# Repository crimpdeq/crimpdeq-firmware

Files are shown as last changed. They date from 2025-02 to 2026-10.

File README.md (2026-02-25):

# Crimpdeq Firmware




Meet [Crimpdeq](https://crimpdeq.com), a portable digital force sensor designed for climbers, coaches, and therapists to measure and train finger strength, pulling power, and endurance.

Crimpdeq is a fully open-source project based on an [ESP32-C3](https://github.com/esp-rs/esp-rust-board) and a WH-C100 crane scale, with firmware fully written in Rust!

> [!NOTE]
> If you're interested in reproducing this project or giving it a try, please, reach out! You can contact me via email (sergio.gasquez@gmail.com), [Twitter](https://x.com/Sergio_Gasquez) or [Bluesky](https://bsky.app/profile/sergiogasquez.bsky.social).

## Specs

- Rechargeable battery with USB‑C charging
- Communicates via Bluetooth Low Energy (BLE)
- Open-source firmware written in Rust
- Open-source PCB design
- Open-source 3D case design
- Automatic sleep when inactive
- Compatible with Tindeq Progressor app ([Android](https://play.google.com/store/apps/details?id=com.progressor&hl=es_419) | [iOS](https://apps.apple.com/es/app/tindeq-progressor/id1380412428))
- Compatible with Frez app (formerly ClimbHarder) ([Android](https://play.google.com/store/apps/details?id=com.holdtight.climbharder&pcampaignid=web_share) | [iOS](https://apps.apple.com/us/app/climbharder-no-hang-training/id6730120024))
- Sampling frequency: 80 Hz
- Design load: 1500 N (≈150 kg), full scale
- Precision:
    - 0.05 kg between 0 and 99 kg
    - 0.1 kg between 100 and 150 kg
- Operating temperature: 0–40 °C
- Dimensions: 80 × 90 × 35 mm
- Uses the [Tindeq Progressor API](https://tindeq.com/progressor_api/)

## Building and Running the Firmware

The [Crimpdeq Book](https://book.crimpdeq.com/) covers assembly, calibration, charging, and general usage. For repository-specific instructions, see the [Firmware](https://book.crimpdeq.com/firmware.html) chapter for prerequisites, how to build, flash, and run the firmware, how to enable logs, and troubleshooting.

## Contributing
Contributions are welcome! Feel free to:
- Submit PRs for bug fixes or new features
- Test and report issues
- Suggest improvements to documentation

## Issues
If you encounter any issue or want to leave any feedback, please [open an issue](https://github.com/crimpdeq/crimpdeq-firmware/issues/new)

## License
This repository is licensed under either of:

- Apache License, Version 2.0 ([LICENSE-APACHE](LICENSE-APACHE) or http://www.apache.org/licenses/LICENSE-2.0)
- MIT license ([LICENSE-MIT](LICENSE-MIT) or http://opensource.org/licenses/MIT)

at your option.

## Kudos
- @bjoernQ for helping me during the development and developing the [`bleps`](https://github.com/bjoernQ/bleps) crate, which was fundamental for this project.
- [hangman](https://github.com/kesyog/hangman) for being an improved version of this project and a great source of inspiration for this project.
- Tindeq for having its API public and allowing for projects like this to exist!

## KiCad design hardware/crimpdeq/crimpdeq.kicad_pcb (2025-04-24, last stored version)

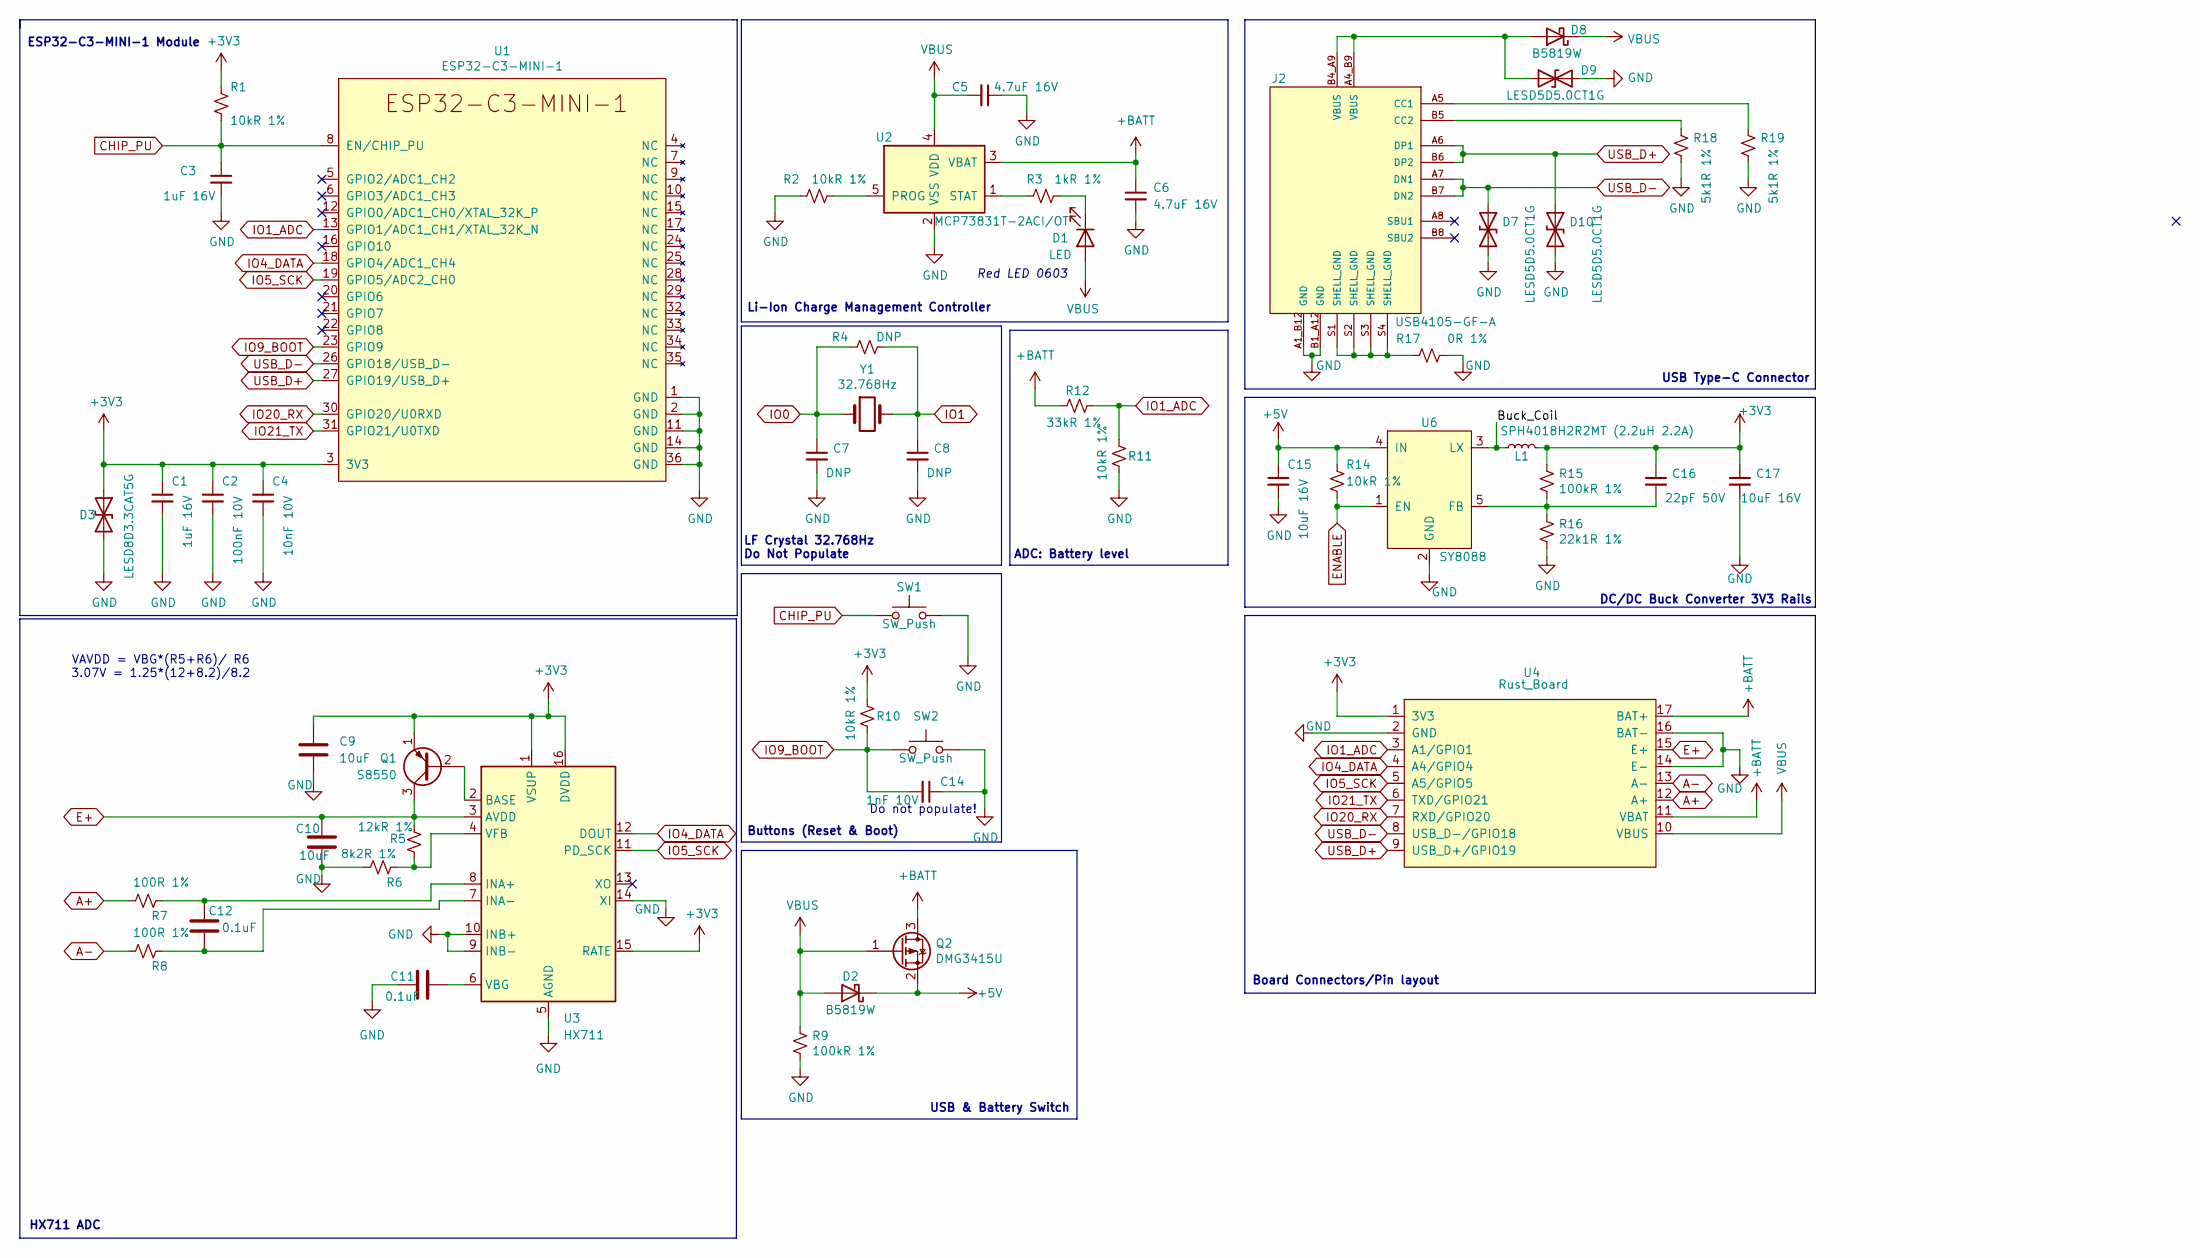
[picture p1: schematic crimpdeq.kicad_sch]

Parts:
C1, C3: 1uF 16V; C_0402_1005Metric; LCSC C52923
C2: 100nF 10V; C_0402_1005Metric; LCSC C1525
C4: 10nF 10V; C_0402_1005Metric; LCSC C15195
C5, C6: 4.7uF 16V; C_0603_1608Metric; LCSC C19666
C7, C8: DNP; C_0402_1005Metric
C9, C10: 10uF; C_0603_1608Metric
C11, C12: 0.1uF; C_0603_1608Metric
C14: 1nF 10V; C_0402_1005Metric; LCSC C1523
C15, C17: 10uF 16V; C_0805_2012Metric; LCSC C15850
C16: 22pF 50V; C_0603_1608Metric; LCSC C1653
D1: LED; LED_0603_1608Metric; LCSC C2286
D2, D8: B5819W; D_SOD-123; LCSC C8598
D3: LESD8D3.3CAT5G; D_SOD-882; LCSC C172409
D7, D9, D10: LESD5D5.0CT1G; D_SOD-523; LCSC C383211
J2: USB4105-GF-A; GCT_USB4105-GF-A; PARTREV A3; LCSC C165948
L1: SPH4018H2R2MT (2.2uH 2.2A); L_Bourns-SRN4018; LCSC C370436
Q1: S8550; TO-92_Inline
Q2: DMG3415U; SOT-23; LCSC C96616
R1, R2, R10, R11, R14: 10kR 1%; R_0402_1005Metric; LCSC C25744
R3: 1kR 1%; R_0402_1005Metric; LCSC C11702
R4: DNP; R_0402_1005Metric
R5: 12kR 1%; R_0402_1005Metric; LCSC C25741
R6: 8k2R 1%; R_0402_1005Metric; LCSC C25741
R7, R8: 100R 1%; R_0402_1005Metric; LCSC C25741
R9, R15: 100kR 1%; R_0402_1005Metric; LCSC C25741
R12: 33kR 1%; R_0402_1005Metric; LCSC C25744
R16: 22k1R 1%; R_0402_1005Metric; LCSC C43473
R17: 0R 1%; R_0402_1005Metric; LCSC C17168
R18, R19: 5k1R 1%; R_0402_1005Metric; LCSC C25905
SW1, SW2: SW_Push; SW_SPST_PTS810; LCSC C116501
U1: ESP32-C3-MINI-1; LCSC C2838502
U2: MCP73831T-2ACI/OT; SOT-23-5; LCSC C424093
U3: HX711; SOP-16_3.9x9.9mm_P1.27mm
U4: Rust_Board
U6: SY8088; SOT-23-5; LCSC C479072
Y1: 32.768Hz; Crystal_SMD_3215-2Pin_3.2x1.5mm

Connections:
+3V3: C1.1, C2.1, C4.1, C9.1, C16.1, C17.1, D3.1 (A1), L1.2, Q1.1 (E), R1.1, R10.1, R15.1, U1.3 (3V3), U3.1 (VSUP), U3.15 (RATE), U3.16 (DVDD), U4.1 (3V3)
+5V: C15.1, D2.1 (K), Q2.2 (S), R14.1, U6.4 (IN)
+BATT: C6.1, Q2.3 (D), R12.1, U2.3 (VBAT), U4.11 (VBAT), U4.17 (BAT+)
/Buck_Coil: L1.1, U6.3 (LX)
A+: R7.2, U4.12 (A+)
A-: R8.2, U4.13 (A-)
CHIP_PU: C3.1, R1.2, SW1.1, U1.8 (EN/CHIP_PU)
E+: C10.1, Q1.3 (C), R5.1, U3.3 (AVDD), U4.15 (E+)
ENABLE: R14.2, U6.1 (EN)
GND: C1.2, C2.2, C3.2, C4.2, C5.1, C6.2, C7.2, C8.2, C9.2, C10.2, C11.1, C14.1, C15.2, C17.2, D3.2 (A2), D7.2 (A2), D9.2 (A2), D10.2 (A2), J2.A1_B12 (GND), J2.B1_A12 (GND), R2.1, R6.2, R9.2, R11.2, R16.2, R17.2, R18.2, R19.2, SW1.2, SW2.2, U1.1 (GND), U1.2 (GND), U1.11 (GND), U1.14 (GND), U1.36 (GND), U1.49, U2.2 (VSS), U3.5 (AGND), U3.9 (INB-), U3.10 (INB+), U3.14 (XI), U4.2 (GND), U4.14 (E-), U4.16 (BAT-), U6.2 (GND)
IO0: C7.1, R4.1, Y1.1
IO1: C8.1, R4.2, Y1.2
IO1_ADC: R11.1, R12.2, U1.13 (GPIO1/ADC1_CH1/XTAL_32K_N), U4.3 (A1/GPIO1)
IO4_DATA: U1.18 (GPIO4/ADC1_CH4), U3.12 (DOUT), U4.4 (A4/GPIO4)
IO5_SCK: U1.19 (GPIO5/ADC2_CH0), U3.11 (PD_SCK), U4.5 (A5/GPIO5)
IO9_BOOT: C14.2, R10.2, SW2.1, U1.23 (GPIO9)
IO20_RX: U1.30 (GPIO20/U0RXD), U4.7 (RXD/GPIO20)
IO21_TX: U1.31 (GPIO21/U0TXD), U4.6 (TXD/GPIO21)
unnamed: D1.1 (K), R3.2
unnamed: D8.2 (A), D9.1 (A1), J2.A4_B9 (VBUS), J2.B4_A9 (VBUS)
unnamed: J2.A5 (CC1), R19.1
unnamed: J2.B5 (CC2), R18.1
unnamed: J2.S1 (SHELL_GND), J2.S2 (SHELL_GND), J2.S3 (SHELL_GND), J2.S4 (SHELL_GND), R17.1
unnamed: Q1.2 (B), U3.2 (BASE)
unnamed: R2.2, U2.5 (PROG)
unnamed: R3.1, U2.1 (STAT)
unnamed: C12.1, R7.1, U3.8 (INA+)
unnamed: C12.2, R8.1, U3.7 (INA-)
unnamed: C11.2, U3.6 (VBG)
unnamed: R5.2, R6.1, U3.4 (VFB)
unnamed: C16.2, R15.2, R16.1, U6.5 (FB)
USB_D+: D10.1 (A1), J2.A6 (DP1), J2.B6 (DP2), U1.27 (GPIO19/USB_D+), U4.9 (USB_D+/GPIO19)
USB_D-: D7.1 (A1), J2.A7 (DN1), J2.B7 (DN2), U1.26 (GPIO18/USB_D-), U4.8 (USB_D-/GPIO18)
VBUS: C5.2, D1.2 (A), D2.2 (A), D8.1 (K), Q2.1 (G), R9.1, U2.4 (VDD), U4.10 (VBUS)

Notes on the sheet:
ADC: Battery level
USB Type-C Connector
VAVDD = VBG*(R5+R6)/ R6 3.07V = 1.25*(12+8.2)/8.2
Board Connectors/Pin layout
Li-Ion Charge Management Controller
USB & Battery Switch
Do not populate!
Red LED 0603
Buttons (Reset & Boot)
HX711 ADC
ESP32-C3-MINI-1 Module
LF Crystal 32.768Hz Do Not Populate
DC/DC Buck Converter 3V3 Rails

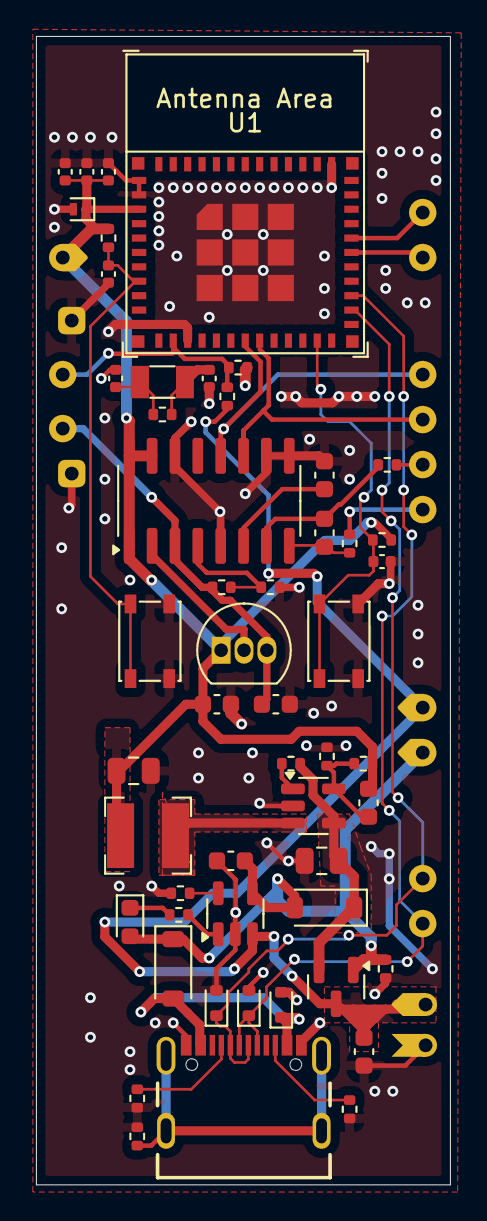
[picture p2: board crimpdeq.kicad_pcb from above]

Board: 2 copper layers, 23.0 x 63.8 mm, 53 parts (0 on the bottom side), 34 nets.

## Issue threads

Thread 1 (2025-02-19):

Improve taring

SergioGasquez, 2025-02-19:
At the moment, the taring mechanism is not ideal, and in the Tindeq app, when switching hands, it gets tared, which results in having it wrongly tared.

SergioGasquez, 2025-03-03:
Also, we should avoid taring if the calibration offset and factor are the defaults

Closed 2025-03-03.

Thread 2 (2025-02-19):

Improve calibration

SergioGasquez, 2025-02-19:
At the moment we don't really calibrate, we just have a [hardcoded value](https://github.com/SergioGasquez/crimpdeq/blob/main/src/bin/main.rs#L66-L67)  as a scale, this value might work for some values, but with higher weights it may not be correct

Closed 2025-02-21.

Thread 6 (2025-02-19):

Evaluate which sampling frequency the HX711 should use

SergioGasquez, 2025-02-19:
If we connect the `RATE` signal of the HX711 to 3.3v, it samples at 80 Hz instead of 10 Hz. See `Table 1 Pin Description` of [Datasheet](https://cdn.sparkfun.com/datasheets/Sensors/ForceFlex/hx711_english.pdf)

Closed 2025-02-26.

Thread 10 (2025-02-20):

Remove unnecesary exposed pins

SergioGasquez, 2025-02-20:
At the moment, the board exposes, via holes, many unnecessary pins. Deleting them would result in less pads and a simpler pcb

Closed 2025-02-26.

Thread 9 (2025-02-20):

Allow connecting a switch to power on/off the device

SergioGasquez, 2025-02-20:
This should be achieved by leaving two holes, where we could solder, two wires that go to the switch. Those 2 holes should be connected to the battery pins.

Closed 2025-02-26.

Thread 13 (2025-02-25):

Update HX711 sampling frequency

SergioGasquez, 2025-02-25:
HX711 can sample at 10Hz and 80Hz, depending on the `RATE` pin value (` 0: 10Hz; 1: 80Hz `). The PCB should use 80 Hz as RFD test only makes sense with high sampling freq.

SergioGasquez, 2025-02-26:
Closed in favor of #13

Closed 2025-02-26.

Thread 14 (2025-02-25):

Evaluate using NAU7802

SergioGasquez, 2025-02-25:
NAU7802 can sample up to 320Hz which is 4 times what HX711 offers:

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

This is very important for an accurate RFD measurement (which usually requires 200/500 Hz). NAU7802 also more expensive than HX711

Closed 2025-02-25.

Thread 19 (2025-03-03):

Add a ControlPoint to reset calibration values

SergioGasquez, 2025-03-03:
The control point should set offset to `0.0` and factor to `1.0`

SergioGasquez, 2025-03-04:
Also, instead of having this we could have a `read_unclaibrated()` method that is used when getting the measured value for the calibration points

Closed 2025-03-27.

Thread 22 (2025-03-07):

thoughts on the schematics

abbbe, 2025-03-07:
I have noticed you use a 1K resistor at ADC input. I am not sure it is a good practice, I mean both use of a single resistor and use of such a high value. I wonder if you saw https://cdn.sparkfun.com/assets/learn_tutorials/3/7/4/SparkFun_openScale_schematic.pdf. Their design -- with two 100R resistors on the inputs -- looks quite sensible. Also note a choke on the excitation line.

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

You are powering HX711 with 3.3V. Supposedly the chip supports this voltage, but many load cells actually rated for higher excitation voltage. No real clue what is the impact in practice, cannot offer any real insight... Just something I was pondering in background as I was also thinking about making custom ESP32+NX711 PCB. This might be useful: https://hackaday.io/project/1741-honeybee-hive-monitoring/log/9780-modifying-the-hx711-breakout-board-for-33v-operation.

Closed 2025-04-24.

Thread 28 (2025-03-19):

Question: Is CALIBRATION_OFFSET needed when using tare?

Yelvd, 2025-03-19:
Calibrated value is calculated using:
```
let raw_value = self.read_raw() - self.tare_value;
let calibrated_value = raw_value as f32 * self.calibration.factor - self.calibration.offset;
```

I am wondering if the `self.calibration.offset` and `self.tare_value` are not both doing the same thing.

Based on the example below, it seems that taring removes the need for the calibration offset

## Example
Assuming the following calibration factors
```
const CALIBRATION_FACTOR: f32 = 0.5;
const CALIBRATION_OFFSET: f32 = 100;
```

### Without Tare:
```
raw_value = read_raw - tare_value = 200 - 0;
calibrated_value = raw_value * calibration.value - calibration.offset =  200 * 0.5 - 100 = 0;
```
This is correct expected behavior.

### With Tare:
tare_value = 200
```
raw_value = read_raw - tare_value = 200 - 200;
calibrated_value = raw_value * calibration.value - calibration.offset =  0 * 0.5 - 100 = -100;
```
Incorrect value.

Yelvd, 2025-03-20:
Thanks for the information. See what the idea is.

To me it looks like at the moment taring is doing both jobs, i.e., the calibration_offset is removed twice.

If that is true, I think there are two main options:

1. Remove CALIBRATION_OFFSET and keep tare as is
2. Keep CALIBRATION_OFFSET, but calculate the tare value over the calibrated value, and remove from calibrated value (instead of from the raw). Because then the tare_value without added weight is 0, so the result would be correct.
 Something like:
```
     // self.tare = is avg of calibrated_value
     let raw_value = self.read_raw();
     let calibrated_value = raw_value as f32 * self.calibration.factor - self.calibration.offset;
     let tared_value = calibrated_value - self.tare_value
```

I don't think any one option is more accurate than the other. And I can imagine that there might be some cases where having the CALIBRATION_OFFSET is useful. But I do think that the current implementation is not fully accurate. But if my logic is wrong, and the current calculation is accurate, then there is no problem.

Closed 2025-07-04.

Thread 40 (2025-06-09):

Wrong values after calibration

Bobr7772, 2025-06-09:
I am following guide book on calibration,but still getting issues with correct weight displayment.

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
+-28kg of added weight
My current calibration cycle:
No weight - 7300000000 - send - hanging weight  -- 7341e0cccd - send - weight release.

SergioGasquez, 2025-06-13:
> I will try

Let me know how it goes!

Bobr7772, 2025-06-13:
How can I put grams instead of kg? I have 28 kg kettlebell,so I will need to put 0x4888b800 into a calibration app?

Bobr7772, 2025-06-14:
I am still getting wrong values.
https://streamable.com/jro9bn video with calibration

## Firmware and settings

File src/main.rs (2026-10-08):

#![no_std]
#![no_main]

use core::cell::RefCell;

use bt_hci::{
    cmd::le::{LeConnUpdate, LeReadLocalSupportedFeatures},
    controller::{ControllerCmdAsync, ControllerCmdSync, ExternalController},
};
use critical_section::Mutex;
use defmt::{debug, error, info, warn};
use embassy_executor::Spawner;
use embassy_futures::{
    join::join,
    select::{Either, select, select3},
};
use embassy_sync::{blocking_mutex::raw::CriticalSectionRawMutex, channel::Channel, watch::Watch};
use embassy_time::{Duration, Timer};
use esp_hal::{
    Async,
    Config,
    clock::CpuClock,
    delay::Delay,
    gpio::{Input, InputConfig, Level, Output, OutputConfig, Pull},
    i2c::master::{Config as I2cConfig, I2c},
    rmt::Rmt,
    rtc_cntl::sleep::{LowPower, RtcSleepConfig},
    time::Rate,
    timer::timg::TimerGroup,
};
use esp_hal_smartled::{RmtSmartLeds, WS2812B_TIMING, buffer_size, color_order};
use esp_radio::ble::controller::BleConnector;
use esp_storage::FlashStorage;
use max170xx::Max17048;
use smart_leds::{RGB8, SmartLedsWriteAsync as _, brightness};
use trouble_host::prelude::*;

use crate::{
    ble::{CONNECTIONS_MAX, DEVICE_NAME, L2CAP_CHANNELS_MAX, L2CAP_MTU, Server, advertise},
    hx711::Hx711,
    progressor::{
        CalibrationPoint,
        ControlOpCode,
        DataPoint,
        DataPointChannel,
        DeviceState,
        LOAD_CELL_COMMANDS,
        LoadCellCommand,
        MAX_CALIBRATION_POINTS,
        MeasurementTaskStatus,
        ResponseCode,
        SleepReadySource,
        SleepReason,
        SleepState,
        WeightMeasurementBatch,
    },
};

pub mod ble;
pub mod hx711;
pub mod progressor;

const STATUS_LED_COUNT: usize = 1;
const STATUS_LED_RMT_BUFFER_SIZE: usize = buffer_size::<RGB8>(STATUS_LED_COUNT);
const STATUS_LED_BRIGHTNESS: u8 = 24;
const STATUS_LED_LOW_BATTERY_MV: u32 = 3500;
/// Charge rate, in %/h, above which the battery counts as charging.
const CHARGING_RATE_THRESHOLD: f32 = 0.1;
/// Battery voltage at or below which the device warns and enters deep sleep. Below about 3.3 V
/// the 3V3 regulator drops out.
const LOW_BATTERY_SHUTDOWN_MV: u32 = 3300;
/// Consecutive low battery readings needed before shutting down, to ignore load transients.
const LOW_BATTERY_SHUTDOWN_READINGS: u8 = 2;
const STATUS_LED_OFF: RGB8 = RGB8 { r: 0, g: 0, b: 0 };
const STATUS_LED_DISCONNECTED: RGB8 = RGB8 { r: 0, g: 0, b: 255 };
const STATUS_LED_CONNECTED: RGB8 = RGB8 { r: 0, g: 255, b: 0 };
const STATUS_LED_LOW_BATTERY: RGB8 = RGB8 { r: 255, g: 0, b: 0 };
/// Delay before retrying failed BLE advertising.
const BLE_RETRY_DELAY: Duration = Duration::from_secs(1);
type StatusLed = RmtSmartLeds<'static, STATUS_LED_RMT_BUFFER_SIZE, Async, RGB8, color_order::Grb>;

#[derive(Clone, Copy, PartialEq)]
enum StatusLedMode {
    Off,
    Disconnected,
    Connected,
    LowBattery,
}

// Helper macro for static allocation
macro_rules! mk_static {
    ($t:ty,$val:expr) => {{
        static STATIC_CELL: static_cell::StaticCell<$t> = static_cell::StaticCell::new();
        #[deny(unused_attributes)]
        let x = STATIC_CELL.uninit().write($val);
        x
    }};
}

/// Static tracking the state of the device
static DEVICE_STATE: Mutex<RefCell<DeviceState>> = Mutex::new(RefCell::new(DeviceState::new()));

/// Logs the panic over RTT. Debug builds then halt so a debugger can inspect the panic; release
/// builds reset the chip, so a panic does not leave the device hung with the radio and peripherals
/// powered.
#[panic_handler]
fn panic(info: &core::panic::PanicInfo) -> ! {
    critical_section::with(|_| {
        error!("{}", defmt::Display2Format(info));

        #[cfg(debug_assertions)]
        loop {
            core::hint::spin_loop();
        }

        #[cfg(not(debug_assertions))]
        esp_hal::system::software_reset()
    })
}

/// Number of tasks that wait for device state changes: measurement, status LED, deep sleep and
/// connection parameters.
const STATE_CHANGE_RECEIVERS: usize = 4;
/// Signals device state changes, so tasks can wait for them instead of polling.
static STATE_CHANGED: Watch<CriticalSectionRawMutex, (), STATE_CHANGE_RECEIVERS> = Watch::new();

/// Updates the device state and, if it changed, wakes the tasks that wait for state changes.
fn update_device_state<R>(update: impl FnOnce(&mut DeviceState) -> R) -> R {
    let (result, changed) = critical_section::with(|cs| {
        let mut state = DEVICE_STATE.borrow_ref_mut(cs);
        let previous = state.clone();
        let result = update(&mut state);
        (result, *state != previous)
    });
    if changed {
        STATE_CHANGED.sender().send(());
    }
    result
}

// ESP-IDF App Descriptor
esp_bootloader_esp_idf::esp_app_desc!();

#[esp_rtos::main]
async fn main(spawner: Spawner) -> ! {
    // Initialize RTT for defmt logging
    rtt_target::rtt_init_defmt!();

    // System initialization
    let config = Config::default().with_cpu_clock(CpuClock::max());
    let peripherals = esp_hal::init(config);

    // Allocate 72KB of heap memory
    esp_alloc::heap_allocator!(size: 72 * 1024);

    // Initialize RTOS
    let timg0 = TimerGroup::new(peripherals.TIMG0);
    esp_rtos::start(timg0.timer0, peripherals.FROM_CPU_INTR0);

    // Initialize BLE
    let bluetooth = peripherals.BT;
    let ble_config =
        esp_radio::ble::Config::default().with_default_tx_power(esp_radio::ble::TxPower::P20);
    let connector = BleConnector::new(bluetooth, ble_config).unwrap();
    let controller: ExternalController<_, 1> = ExternalController::new(connector);

    // Initialize load cell pins
    let clock_pin = Output::new(peripherals.GPIO5, Level::Low, OutputConfig::default());
    let data_pin = Input::new(
        peripherals.GPIO4,
        InputConfig::default().with_pull(Pull::None),
    );
    let delay = Delay::new();

    // Initialize Flash Storage
    let flash = FlashStorage::new(peripherals.FLASH);

    // Initialize low-power control.
    let low_power = LowPower::new(peripherals.LPWR);

    // Initialize MAX17048 fuel gauge over I2C.
    // PCB nets are labelled IO6_SDA/IO7_SCL, but the MAX17048 TDFN datasheet maps
    // pin 7 to SCL and pin 8 to SDA while the KiCad symbol had those two swapped.
    // Actual gauge connections: GPIO7=SDA, GPIO6=SCL, GPIO10=/ALRT,
    // CELL/VDD=+BATT, QSTRT=GND. /ALRT is open-drain and has no external pull-up.
    let _battery_alert_pin = Input::new(
        peripherals.GPIO10,
        InputConfig::default().with_pull(Pull::Up),
    );
    let battery_i2c = I2c::new(peripherals.I2C0, I2cConfig::default())
        .expect("Failed to initialize battery I2C")
        .with_sda(peripherals.GPIO7)
        .with_scl(peripherals.GPIO6)
        .into_async();
    let battery_gauge = Max17048::new(battery_i2c);

    // Initialize WS2812B status LED on GPIO2 using RMT.
    let status_led_rmt_rate = Rate::from_mhz(80);
    let rmt = Rmt::new(peripherals.RMT, status_led_rmt_rate)
        .expect("Failed to initialize RMT")
        .into_async();
    let status_led = StatusLed::new(
        WS2812B_TIMING,
        rmt.channel0,
        peripherals.GPIO2,
        status_led_rmt_rate,
    )
    .expect("Failed to initialize status LED");

    // Use the last 6 bytes of the DEVICE_NAME for the address
    let name_bytes = DEVICE_NAME.as_bytes();
    let mut address_seed = [0u8; 6];
    let seed_len = address_seed.len();
    if name_bytes.len() >= seed_len {
        address_seed.copy_from_slice(&name_bytes[name_bytes.len() - seed_len..]);
    } else {
        address_seed[..name_bytes.len()].copy_from_slice(name_bytes);
    }
    address_seed[5] |= 0xC0;
    let address: Address = Address::random(address_seed);
    let mut resources: HostResources<
        DefaultPacketPool,
        CONNECTIONS_MAX,
        L2CAP_CHANNELS_MAX,
        L2CAP_MTU,
    > = HostResources::new();
    let stack = trouble_host::new(controller, &mut resources)
        .set_random_address(address)
        .build();
    let mut peripheral = stack.peripheral();
    let runner = stack.runner();

    info!("Starting advertising and GATT service");
    let server = Server::new_with_config(GapConfig::Peripheral(PeripheralConfig {
        name: DEVICE_NAME,
        appearance: &appearance::UNKNOWN,
    }))
    .unwrap();

    // Data point channel for communication between tasks
    let channel = mk_static!(DataPointChannel, Channel::new());

    // Start inactivity tracking from boot so the device can auto-sleep if left unused.
    update_device_state(|state| state.on_ble_disconnected());

    // Spawn tasks
    spawner.spawn(measurement_task(channel, clock_pin, data_pin, delay, flash).unwrap());
    spawner.spawn(battery_gauge_task(battery_gauge, channel).unwrap());
    spawner.spawn(status_led_task(status_led).unwrap());
    spawner.spawn(deep_sleep_task(low_power).unwrap());

    join(ble_task(runner), async {
        loop {
            match advertise(&mut peripheral, &server).await {
                Ok(conn) => {
                    info!("BLE connection established");

                    channel.clear();
                    update_device_state(|state| state.on_ble_connected());
                    // run until any task ends (usually because the connection has been closed),
                    // then return to advertising state.
                    select3(
                        gatt_events_task(&server, &conn, channel),
                        data_processing_task(&server, &conn, channel),
                        connection_params_task(&stack, &conn),
                    )
                    .await;
                    channel.clear();
                    update_device_state(|state| {
                        state.stop_measurement();
                        state.on_ble_disconnected();
                        debug!("BLE connection closed, inactivity timer restarted");
                    });
                }
                Err(e) => {
                    error!("BLE advertising failed: {:?}", defmt::Debug2Format(&e));
                    Timer::after(BLE_RETRY_DELAY).await;
                }
            }
        }
    })
    .await;

    unreachable!("BLE tasks never return")
}

/// Runs the BLE host.
///
/// Running the host again starts with an HCI reset, which stops advertising and drops the
/// connection that the rest of the BLE code still waits on. A failure resets the chip instead, so
/// the whole BLE stack restarts together.
async fn ble_task<C: Controller, P: PacketPool>(mut runner: Runner<'_, C, P>) {
    if let Err(e) = runner.run().await {
        error!("BLE runner failed: {:?}", defmt::Debug2Format(&e));
    }
    error!("BLE runner stopped, resetting");
    esp_hal::system::software_reset()
}

fn status_led_mode() -> StatusLedMode {
    critical_section::with(|cs| {
        let state = DEVICE_STATE.borrow_ref(cs);
        if state.sleep_state != SleepState::Awake {
            StatusLedMode::Off
        } else if state.battery_voltage <= STATUS_LED_LOW_BATTERY_MV {
            StatusLedMode::LowBattery
        } else if state.is_ble_connected() {
            StatusLedMode::Connected
        } else {
            StatusLedMode::Disconnected
        }
    })
}

async fn set_status_led(led: &mut StatusLed, color: RGB8) {
    if let Err(e) = led
        .write(brightness([color].into_iter(), STATUS_LED_BRIGHTNESS))
        .await
    {
        warn!(
            "Failed to update WS2812B status LED: {:?}",
            defmt::Debug2Format(&e)
        );
    }
}

#[embassy_executor::task]
async fn status_led_task(mut led: StatusLed) {
    let mut state_changes = STATE_CHANGED
        .receiver()
        .expect("Missing state change receiver for the status LED task");
    set_status_led(&mut led, STATUS_LED_OFF).await;
    let mut current_mode = StatusLedMode::Off;
    let mut sleep_led_ready = false;

    loop {
        let sleep_state = critical_section::with(|cs| DEVICE_STATE.borrow_ref(cs).sleep_state);
        match sleep_state {
            SleepState::Requested(reason) => {
                if !sleep_led_ready {
                    info!("Turning off status LED before deep sleep: {:?}", reason);
                    set_status_led(&mut led, STATUS_LED_OFF).await;
                    current_mode = StatusLedMode::Off;
                    sleep_led_ready = true;
                    update_device_state(|state| {
                        state.mark_sleep_ready(SleepReadySource::StatusLed)
                    });
                }
                state_changes.changed().await;
                continue;
            }
            SleepState::Ready(_) => {
                state_changes.changed().await;
                continue;
            }
            SleepState::Awake => {
                sleep_led_ready = false;
            }
        }

        let mode = status_led_mode();
        if mode == StatusLedMode::LowBattery {
            // Blink until the state changes.
            set_status_led(&mut led, STATUS_LED_LOW_BATTERY).await;
            if let Either::First(_) = select(
                Timer::after(Duration::from_millis(250)),
                state_changes.changed(),
            )
            .await
            {
                set_status_led(&mut led, STATUS_LED_OFF).await;
                select(
                    Timer::after(Duration::from_millis(750)),
                    state_changes.changed(),
                )
                .await;
            }
            current_mode = StatusLedMode::LowBattery;
            continue;
        }

        // Only write the LED when its color changes.
        if mode != current_mode {
            let color = match mode {
                StatusLedMode::Off | StatusLedMode::LowBattery => STATUS_LED_OFF,
                StatusLedMode::Disconnected => STATUS_LED_DISCONNECTED,
                StatusLedMode::Connected => STATUS_LED_CONNECTED,
            };
            set_status_led(&mut led, color).await;
            current_mode = mode;
        }
        state_changes.changed().await;
    }
}

#[embassy_executor::task]
async fn deep_sleep_task(mut low_power: LowPower<'static>) {
    const IDLE_TIMEOUT_MS: u32 = 4 * 60 * 1000; // 4 minutes
    const DEEP_SLEEP_FAILSAFE_SECS: u64 = 10 * 365 * 24 * 60 * 60;

    let mut state_changes = STATE_CHANGED
        .receiver()
        .expect("Missing state change receiver for the deep sleep task");

    loop {
        let (sleep_state, measurement_status, inactivity_ms, ble_connected) =
            critical_section::with(|cs| {
                let state = DEVICE_STATE.borrow_ref(cs);
                (
                    state.sleep_state,
                    state.measurement_status,
                    state.get_inactivity_elapsed_ms(),
                    state.is_ble_connected(),
                )
            });

        match sleep_state {
            SleepState::Awake => {
                if measurement_status == MeasurementTaskStatus::Disabled {
                    debug!(
                        "Device idle for {:?} ms (connected: {}, timeout: {:?} ms)",
                        inactivity_ms, ble_connected, IDLE_TIMEOUT_MS
                    );

                    if inactivity_ms >= IDLE_TIMEOUT_MS {
                        update_device_state(|state| state.request_sleep(SleepReason::IdleTimeout));
                        continue;
                    }

                    // Wait for the idle timeout or for activity that restarts it.
                    let remaining_ms = IDLE_TIMEOUT_MS - inactivity_ms;
                    select(
                        Timer::after(Duration::from_millis(remaining_ms.into())),
                        state_changes.changed(),
                    )
                    .await;
                } else {
                    state_changes.changed().await;
                }
            }
            SleepState::Requested(reason) => {
                debug!(
                    "Waiting for peripherals to power down before sleep: {:?}",
                    reason
                );
                state_changes.changed().await;
            }
            SleepState::Ready(reason) => {
                info!("Entering deep sleep: {:?}", reason);
                Timer::after(Duration::from_millis(20)).await;
                // Drive the WS2812B data line low and hold it so the LED does not latch
                // noise while the digital domain is powered off.
                // SAFETY: the status LED is already off and its task stops writing once sleep
                // is ready. No await follows, so it cannot run again before `sleep_deep`, which
                // does not return; the hold is released on the next boot.
                let mut status_led_pin = Output::new(
                    unsafe { esp_hal::peripherals::GPIO2::steal() },
                    Level::Low,
                    OutputConfig::default(),
                );
                status_led_pin.set_pad_hold(true);
                low_power.set_wakeup_deadline(
                    esp_hal::time::Instant::now()
                        + esp_hal::time::Duration::from_secs(DEEP_SLEEP_FAILSAFE_SECS),
                );
                low_power.sleep_deep(RtcSleepConfig::deep());
            }
        }
    }
}

#[embassy_executor::task]
async fn battery_gauge_task(
    mut gauge: Max17048<I2c<'static, Async>>,
    channel: &'static DataPointChannel,
) {
    let mut low_battery_readings = 0;

    loop {
        let voltage = gauge.voltage().await;
        let soc = gauge.soc().await;
        let charge_rate = gauge.charge_rate().await;

        match (voltage, soc, charge_rate) {
            (Ok(voltage), Ok(soc), Ok(charge_rate)) => {
                let battery_voltage_mv = (voltage * 1000.0) as u32;
                let battery_charging = charge_rate > CHARGING_RATE_THRESHOLD;
                info!(
                    "Battery: {:?} mV, SOC: {:?}%, charge rate: {:?}%/h",
                    battery_voltage_mv, soc, charge_rate
                );

                // Update device state
                let ble_connected = update_device_state(|state| {
                    state.battery_voltage = battery_voltage_mv;
                    state.is_ble_connected()
                });

                if battery_voltage_mv <= LOW_BATTERY_SHUTDOWN_MV && !battery_charging {
                    low_battery_readings += 1;
                } else {
                    low_battery_readings = 0;
                }

                if low_battery_readings >= LOW_BATTERY_SHUTDOWN_READINGS {
                    warn!(
                        "Battery at {:?} mV, entering deep sleep",
                        battery_voltage_mv
                    );
                    if ble_connected {
                        if channel
                            .try_send(DataPoint::from(ResponseCode::LowPowerWarning))
                            .is_err()
                        {
                            warn!("Failed to queue low power warning");
                        }
                        // Give the notification time to reach the client.
                        Timer::after(Duration::from_millis(500)).await;
                    }
                    update_device_state(|state| state.request_sleep(SleepReason::LowBattery));
                }
            }
            (voltage, soc, charge_rate) => {
                warn!(
                    "Failed to read MAX17048 battery gauge: voltage={:?}, soc={:?}, charge_rate={:?}",
                    defmt::Debug2Format(&voltage),
                    defmt::Debug2Format(&soc),
                    defmt::Debug2Format(&charge_rate)
                );
            }
        }

        Timer::after(Duration::from_secs(45)).await;
    }
}
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

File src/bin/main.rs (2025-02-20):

#![no_std]
#![no_main]

use bleps::{
    ad_structure::{
        create_advertising_data, AdStructure, BR_EDR_NOT_SUPPORTED, LE_GENERAL_DISCOVERABLE,
    },
    async_attribute_server::AttributeServer,
    asynch::Ble,
    attribute_server::NotificationData,
    gatt,
    no_rng::NoRng,
};
use bytemuck::bytes_of;
use core::cell::RefCell;
use critical_section::Mutex;
use defmt::{debug, error, info};
use defmt_rtt as _;
use embassy_executor::Spawner;
use embassy_sync::channel::Channel;
use embassy_time::{Duration, Timer};
use esp_alloc as _;
use esp_backtrace as _;
use esp_hal::{
    clock::CpuClock,
    delay::Delay,
    gpio::{Input, InputConfig, Level, Output, OutputConfig, Pull},
    rng::Rng,
    time,
    timer::{systimer::SystemTimer, timg::TimerGroup},
    Config,
};
use esp_println as _;
use esp_wifi::{ble::controller::BleConnector, init, EspWifiController};
// use loadcell::{hx711, LoadCell};

use crimpdeq::{
    hx711::Hx711,
    progressor::{ControlOpCode, DataPoint, DataPointChannel, ResponseCode, SCAN_RESPONSE_DATA},
};

macro_rules! mk_static {
    ($t:ty,$val:expr) => {{
        static STATIC_CELL: static_cell::StaticCell<$t> = static_cell::StaticCell::new();
        #[deny(unused_attributes)]
        let x = STATIC_CELL.uninit().write(($val));
        x
    }};
}

/// Status of the weigth measurement task
#[derive(Copy, Debug, Clone, PartialEq)]
enum MeasurementTaskStatus {
    /// Measurements are enabled
    Enabled,
    /// Measurements are disabled
    Disabled,
    /// Taring the scale
    ///
    /// Used in ClimbHarder App
    Tare,
    /// Soft taring the scale (substract the current weight)
    ///
    /// Used in Tindeq App
    SoftTare,
}

/// Static tracking the state of the measurement task
static MEASUREMENT_TASK_STATUS: Mutex<RefCell<MeasurementTaskStatus>> =
    Mutex::new(RefCell::new(MeasurementTaskStatus::Disabled));
/// Static tracking if the device was tared/soft tared
static DEVICE_TARED: Mutex<RefCell<bool>> = Mutex::new(RefCell::new(false));

// Calibration value. Obtained measuring a few known weights and adjusting the value
const CALIBRATION: f32 = 1.26;

#[esp_hal_embassy::main]
async fn main(spawner: Spawner) -> ! {
    let config = Config::default().with_cpu_clock(CpuClock::max());
    let peripherals = esp_hal::init(config);

    // Allocate 72KB of heap memory
    esp_alloc::heap_allocator!(size: 72 * 1024);

    let timg0 = TimerGroup::new(peripherals.TIMG0);
    let esp_wifi_ctrl = &*mk_static!(
        EspWifiController<'static>,
        init(
            timg0.timer0,
            Rng::new(peripherals.RNG),
            peripherals.RADIO_CLK,
        )
        .unwrap()
    );

    // Load cell pins
    let clock_pin = Output::new(peripherals.GPIO5, Level::Low, OutputConfig::default());
    let data_pin = Input::new(
        peripherals.GPIO4,
        InputConfig::default().with_pull(Pull::None),
    );
    let delay = Delay::new();

    // Initialize embassy
    let systimer = SystemTimer::new(peripherals.SYSTIMER);
    esp_hal_embassy::init(systimer.alarm0);

    // BLE Connector
    let connector = BleConnector::new(esp_wifi_ctrl, peripherals.BT);

    // Data point channel
    let channel = mk_static!(DataPointChannel, Channel::new());

    // Spawn tasks
    spawner.spawn(bt_task(connector, channel)).unwrap();
    spawner
        .spawn(measurement_task(channel, clock_pin, data_pin, delay))
        .unwrap();

    // Wait forever
    loop {
        Timer::after(Duration::from_millis(50)).await;
    }
}

#[embassy_executor::task]
async fn bt_task(connector: BleConnector<'static>, channel: &'static DataPointChannel) {
    let now = || time::Instant::now().duration_since_epoch().as_millis();
    let mut ble = Ble::new(connector, now);
    loop {
        // Reset the state of the measurement task
        critical_section::with(|cs| {
            *MEASUREMENT_TASK_STATUS.borrow_ref_mut(cs) = MeasurementTaskStatus::Disabled;
        });
        info!("Starting BLE");
        debug!("Initializing BLE");
        ble.init().await.unwrap();
        debug!("Setting advertising parameters");
        ble.cmd_set_le_advertising_parameters().await.unwrap();
        debug!("Setting advertising data");
        ble.cmd_set_le_advertising_data(
            create_advertising_data(&[
                AdStructure::Flags(LE_GENERAL_DISCOVERABLE | BR_EDR_NOT_SUPPORTED),
                AdStructure::CompleteLocalName(env!("DEVICE_NAME")),
            ])
            .unwrap(),
        )
        .await
        .unwrap();
        debug!("Setting scan response data");
        ble.cmd_set_le_scan_rsp_data(Data::new(SCAN_RESPONSE_DATA))
            .await
            .unwrap();
        debug!("Setting advertising enable");
        ble.cmd_set_le_advertise_enable(true).await.unwrap();

        info!("Started advertising");

        // Service/Characteristics Read/Write methods
        let mut control_point_write = |_, data: &[u8]| {
            let op_copde = ControlOpCode::from(data[0]);
            info!("Control Point Received: {:?}", op_copde);
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

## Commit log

2025-01-18 feat: Avoid using raw advertising data
    [main.rs]
2025-01-20 feat: Add initial calibration
2025-01-22 feat: Remove to_le_bytes_without_trailing_zeros, arrayvec dep and ResponseCode::CalibrationCurve
2025-01-24 feat: add hx711 driver
2025-01-28 pcb: Initial schematic
    [crimpdeq.kicad_pcb, crimpdeq.kicad_sch]
2025-01-28 pcb: Initial PCB design
    [crimpdeq.kicad_pcb, crimpdeq.kicad_sch]
2025-01-28 pcb: Initial placing of hx711
    [crimpdeq.kicad_pcb]
2025-01-29 pcb: Initial wiring of pcb
    [crimpdeq.kicad_pcb, crimpdeq.kicad_sch]
2025-02-20 feat: Avoid sof taring when taring is done
    [main.rs]
2025-02-21 Calibrate the scale (#11)
    * feat: Setup calibration
    * feat: Implement calibration
    * revert: defmt level
    * feat: Update calibration
    * chore: Rename method to read_calibrated
    * feat: Reduce visibility of methods
    * feat: Update constants
    [main.rs]
2025-02-26 [PCB]: Remove unused exposed pins and connect hx711/RATE to 3.3v (#15)
    * pcb: Remove unused exposed pins and connect hx711/RATE to 3.3v
    * ci: Dont run Rust CI when updating the pcb
    [crimpdeq.kicad_pcb, crimpdeq.kicad_sch]
2025-02-27 Create PCB layout (#16)
    * pcb: Update layout
    * pcb: Fix DRC unconnected items
    * pcb: More DRC fixes
    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
    [crimpdeq.kicad_pcb, crimpdeq.kicad_sch]
2025-02-27 pcb: DRC issues from PCB layout
    [crimpdeq.kicad_pcb]
2025-02-27 feat: Add KiCad gitignore
2025-03-02 Improve sampling freq (#18)
    * feat: Improve sampling freq
    * perf: Avoid having 2 cs
    * fix: Typo
    * feat: Update taring method
    * feat: Simplify taring method
    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
    [main.rs]
2025-03-07 Rearrange modules and fix timestamps (#24)
    * feat: Create DeviceState and simplify sending DataPoints
    * feat: Simplify bt_task and add ControlOpCode::porcess
    * fix: Properly intialize the start_time
    [main.rs]
2025-03-17 Add an mdbook (#26)
    * docs: Initial version of the book
    * feat: Add battery and calibbration chapters
    * ci: Add book CI
2025-03-18 docs: Update calibration steps
2025-03-27 feat: Allow calibrating via ble
2025-03-27 docs: Updage calibration
2025-03-27 docs: Update calibration instructions
2025-03-27 feat: Use an nvs partition to store the calibration
    [partition.csv]
2025-03-27 feat: Use default nvs partition table
    [partition.csv]
2025-03-27 feat: Add a default calibration method
2025-03-27 feat: Add a fallback to default calibration
2025-03-27 feat: Enhance error handling and improve response code documentation
    [main.rs]
2025-03-27 fix: Simplify error logging for advertising data creation
    [main.rs]
2025-03-27 fix: Enhance error handling in calibration and advertising data processes
    [main.rs]
2025-04-01 feat: Send a hardcoded battery level
2025-04-01 feat: Update calibration points to use Option type
2025-04-01 feat: Use device name for BLE advertising and implement random BLE address generation
2025-04-02 Code cleanups (#34)
    * build: Update deps and remove unused
    * fix: Remove unused comment
    * build: Remove unused features
    [main.rs]
2025-04-03 feat: Improve DEVICE_ID parsing
2025-04-24 Update hx711 schematic according to the datasheet (#35)
    * pcb: Update hx711 schematic according to the datasheet
    * feat: Generate gerber files
    * feat: Regenerate production files
    [crimpdeq-B_Cu.gbr, crimpdeq-B_Mask.gbr, crimpdeq-B_Paste.gbr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]
2025-07-04 Remove calibration offset (#38)
    * feat: Remove calibration offset
    * feat: Tare the scale when initializing it
    * feat: Clippy lints
2025-10-14 Update dependencies to latest `esp-hal@1.0.0-rc.1` (#42)
    * build: Update deps
    * feat: Update how we handle flash
    * feat: Update deps to latest esp-hal rev
    * build: Remover esp-println
    * feat: Remove unnecesary defmt::Debug2Format calls
    * build: Update trouble
    * fix: Lints
    * docs: Update frez name
    * build: Use released crates
    * build: Update trouble-host
    * feat: Remove unnecesary config
    [main.rs]
2025-12-29 Add battery voltage reading and deep sleep support (#43)
    * feat: Implement battery voltage reading
    * feat: Average battery voltage readings over multiple samples
    * fix: Use u32 to avoid overflow
    * feat: Put the device into deep_sleep after 5 mins of ble disconnected
    * feat: Minor improvements
    * feat: Put the device in deepsleep if it doesnt connect in 5 mins
    [main.rs]
2025-12-30 chore: Delete assets and hardware folder
    [crimpdeq-B_Cu.gbr, crimpdeq-B_Mask.gbr, crimpdeq-B_Paste.gbr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]
2026-01-05 fix: Typo and redability
    [main.rs]
2026-02-06 fix: Heap allocation and clippy lints
    [main.rs]
2026-02-08 fix: Remove unnecesary probe-rs arg and avoid double CI run
2026-02-08 feat: Avoid unwrap and improve calibration logging
    [main.rs]
2026-02-10 Support multi-point calibration, store points, and log points and send to app on GetCalibration (#46) (#47)
    * Support multi-point calibration with stored points
    * style: Cargo fmt
2026-02-11 fix: Format and rebase
    [main.rs]
2026-02-13 Add calibration report for Crimpdeq app (#49)
    * feat: Report calibration values
    * refactor: Remove unused tared field and simplify measurement state management
    * feat: Bump crimpdeq version
2026-02-16 feat: Update default calibration
2026-02-23 feat: Update device version number
2026-04-13 Fix BLE advertising and harden sensor handling (#50)
    * fix: correct ble scan response
    * fix: harden sensor and command handling
    * fix: clear queued notifications on reconnect
    * fmt: FIx cargo fmt
    [main.rs]
2026-05-01 Update deps to esp-hal@1.1 and company (#51)
    * build: Update deps to esp-hal@1.1
    * feat: Make the ble connection more reliable
    * feat: batch weight samples in BLE packets
    * feat: Update default calibration factor
    * fix: improve idle sleep behavior
    * build: add cargo flash alias
    * fix: Fmt and clippy
    * Apply suggestions from code review
    * perf: avoid cloning measurement batches
    * build: Use esp-hal@1.1.0
    ---------
    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
    [main.rs]
2026-07-31 Revision 2 (#53)
    * feat: add ws2812b status led
    * fix: reset state on shutdown command
    * feat: use max17048 battery gauge
    * fix: correct battery gauge pin mapping
    * build: update smartled git source
    * fix: remove charging status led state
    * fix: coordinate shutdown and sleep readiness
    [main.rs]
2026-10-08 Release v2.1.0 (#72)
    * fix: hold HX711 clock and LED data pads during deep sleep (#65)
    * fix: hold HX711 clock and LED data pads during deep sleep
    * Settle HX711 readings and power it down when idle (#66)
    * fix: settle HX711 readings and power it down when idle
    * fix: retry HX711 settling after a failed wake
    * Queue tare and calibration commands (#67)
    * fix: queue tare and calibration commands
    * fix: flush samples before commands and restart timestamps per measurement
    * Fix calibration storage, Shutdown and low-battery handling (#68)
    * fix: store calibration in a dedicated partition
    * fix: enter deep sleep on shutdown and low battery
    * Reset on panic and retry failed BLE operations (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
    [partitions.csv]
2026-10-16 Revision 3 (#76)
    * feat: support revision 3 ADS1220 front end
    Replace the HX711 integration with the revision 3 SPI ADC while preserving calibration, measurement pacing, and sleep behavior.
    * feat: increase ADS1220 sampling to 600 SPS
    Preserve calibration averaging windows and tighten BLE connection timing to sustain the higher measurement rate.
    * perf: decouple sampling from BLE transport
    Keep 600 Hz acquisition non-blocking with a drop-oldest measurement ring, prioritize control responses, and reduce ADS1220 SPI overhead.
    * perf: adapt mea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
2026-10-18 feat: add a command to remove a calibration point (#96)
    * feat: add a command to remove a calibration point
    * feat: reply whether a calibration point was removed
    * fix: answer a removal the command queue drops
2026-10-19 fix: buffer full measurement batches at any ATT MTU (#97)
    At ATT MTU 23 the ring held 80 two-sample packets, 160 ms at 1000 SPS,
    which overflowed before the 15 ms measuring interval replaced the idle
    30-50 ms one and lost about 250 samples at the start of each
    measurement.
    The measurement task now always fills batches of up to 10 samples,
    still capped at 50 ms of samples, and data_processing_task splits each
    batch into packets that fit the current ATT MTU. The ring holds 800
    samples at any MTU in slightly less RAM. At MTU 23 a 1000 SPS batch now
    waits 10 ms instead of 2 ms, as at larger MTUs.
    Closes #94
2026-10-19 docs: update readme for PCB V3 and firmware v3.0.0 (#98)
    * docs: update readme for PCB V3 and firmware v3.0.0
    * docs: remove pin map, BLE protocol, and power sections from readme
2026-10-27 build: flash without monitoring when defmt logging is off (#102)
    * build: flash without monitoring when defmt logging is off
    probe-rs 0.32 `run` always monitors the target serial port, and only a
    .probe-rs.toml file can disable it. The runner script now flashes and
    starts the firmware with `probe-rs download --start` when DEFMT_LOG is
    off, and keeps `probe-rs run` when a log level is set.
    Remove the `flash` alias: it shadows probe-rs's cargo-flash, which Cargo
    will reject, and `cargo run` now covers flashing over USB-JTAG.
    * build: reset after flashing with any probe-rs version
    `probe-rs download` resets with `--reset` in the v0.32.0 release and with
    `--start` in newer versions, so the r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
2026-10-27 feat: add a mock build for PCB V3 and the ESP32-C3 Rust board (#101)
    * feat: support the ESP32-C3 Rust board with mocked load cell and battery
    * feat: skip idle deep sleep on the Rust board
    * feat: restart the simulated pulls at every measurement start
    A tare or calibration woke the load cell before the measurement started,
    so the cycle went on from where it was and each run saw other pulls.
    * feat: run the mock build on PCB V3 as well as the Rust board
    * fix: calibrate the mock load cell with the client's weight
2026-10-27 fix: carry 1000 SPS to Android phones (#103)
    An Android phone sent about one 10-sample packet per 15 ms connection
    event, 300 samples/s, so at 1000 SPS the measurement ring overflowed and
    dropped about half the samples. Packets now carry up to 30 samples, as many
    as a 247-byte ATT MTU fits, and each connection asks for 251-byte link
    layer packets and the 2M PHY. On a Xiaomi phone the app then received the
    full 1000 samples/s with no batch dropped.
